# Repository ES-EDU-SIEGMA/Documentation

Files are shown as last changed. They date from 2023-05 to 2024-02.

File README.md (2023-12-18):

# Drink Mixing Machine

This is the project repository of the Drink Mixing Machine.

## Structure

The code for the controller can be found under [Embedded Controller](https://github.com/ES-EDU-SIEGMA/Embedded-Controller), whereas the GUI code can found under [User Interface](https://github.com/ES-EDU-SIEGMA/User-Interface).

The documentation of the hardware and software is provided in this Repository under [documentation](./documentation).
Referenced Datasheets for the Hardware are stored under [datasheets](./datasheets).

The CAD/STL files for the 3D printed parts are stored in the [3D printed parts](./3D_printed_parts) folder.

## Issues

The issues and user stories can be found under [Projects Board](https://github.com/orgs/ES-EDU-SIEGMA/projects/1).
Each Issue is connected to a Repository which it concerns.

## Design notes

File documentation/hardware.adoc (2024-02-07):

= Hardware
:icons: font
:toc: top
:toclevels: 4
:stem:
:imagesdir: images
:figure-caption!:

The Drink Mixing Machine consists of several hardware parts.
There can be grouped into three categories, namely:

* <<Frame,Frame>>
* <<Dispenser Components,Dispenser Components>>
* <<Controlling Components,Controlling Components>>

== Frame

The frame is build from aluminium bases system profiles.

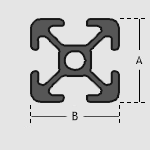
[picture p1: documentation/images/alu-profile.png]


== Dispenser Components

The dispenser group consists of multiple components arranged around a standard bar dispenser as seen in <<dispenser-img,Dispenser Image>>.

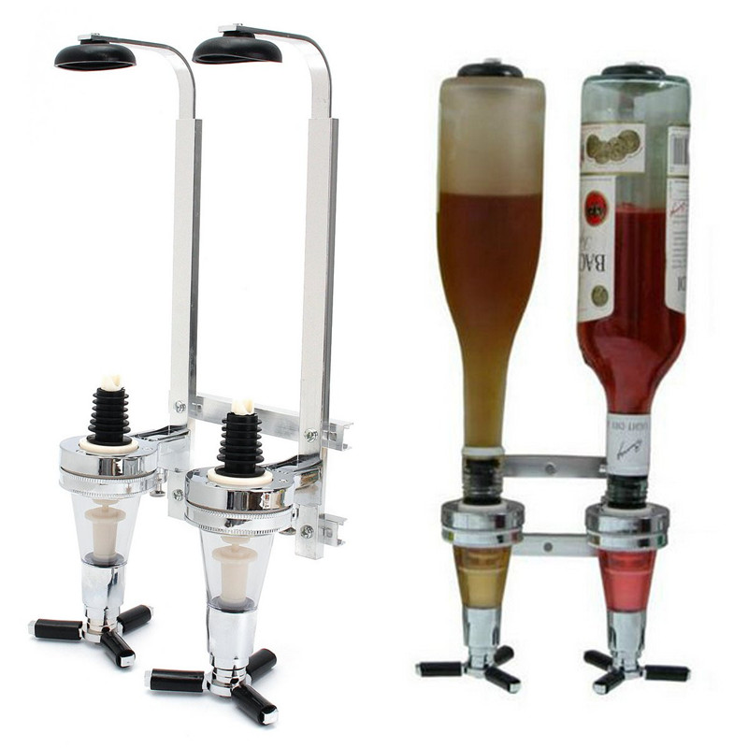
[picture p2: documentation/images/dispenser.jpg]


The dispenser is actuated by a 3D-printed arm which is lifted with a construction of ropes and pulleys powered by a stepper motor as the winch.

=== Metrics

.Manual Operation
====
3 to 5 seconds for the Dispenser to drain the liquid +
**=> 4 to 6 seconds to empty the Dispenser**
====

.With the Machine
====
With a `VACTUAL` (<<TMC2209>>) of 5000 latexmath:[\frac{\mu\text{-steps}}{\text{second}}], the dispenser requires 8 seconds to move up and 8 to move down +
**=> latexmath:[\geq] 16 seconds to empty a Dispenser**

The highest speed that the motor can achieve is `VACTUAL` = 150000 latexmath:[\frac{\mu\text{-steps}}{t}]. With this speed it takes only 6.5 seconds to empty and refill a 4 cl Dispenser.
However, these speeds can only be achieved with a more stable mechanical system. 
Currently, the plastic bottle holders bend to much at higher speeds.
If the dispensers are held from above when starting the motor, it is possible to start up with 150000 latexmath:[\frac{\mu\text{-steps}}{t}]. 
Metal components with a proper attachment to the machine might fix this problem.

IMPORTANT: The current mechanical system allows for speeds of up to  `VACTUAL` = 100000 latexmath:[\frac{\mu\text{-steps}}{t}] for reliable emptying of the dispenser. +
**=> 8 seconds to empty a Dispener**

CAUTION: Slow movement when closing is required in order to assure that the Dispenser is refilled. 
`VACTUAL` = 100000 latexmath:[\frac{\mu\text{-steps}}{t}] should not be exceeded.
====

.Estimated Times to fill a 250ml glass
|===
|Dispenser |Manual Operation |Machine `VACTUAL`=50000 |Machine `VACTUAL`=100000

|3cl |30s |90s |45s

|4cl |24s |72s |36s

|5cl |18s |54s |27s
|===

TIP: 5cl Dispenser can significantly reduce the time required to dispense liquids with large amounts.

==== Real World Test

.Mixing a Cocktail with 5 ingredients:
- 3 ingredients require 2cl each
- 2 ingredients require 10cl each

-> two runs are required with each 18 seconds +
**=> 36 seconds**

=== Improvements

The accuracy of the dispensing mechanism mostly depends on the volume of the dispenser.
Due to hardware restrictions it is extremely difficult to precisely empty the dispenser only partially.

TIP: After improvements to the movement speeds of the motor experiments should take place, that evaluates the possibilty of emptying the dispenser only partially.

== Controlling Components

The controlling components of the machine are a Raspberry Pi (as the main controller) combined with a custom PCB that features a Tiny2040 as a controller for up to 4 stepper drivers and multiple sensors.

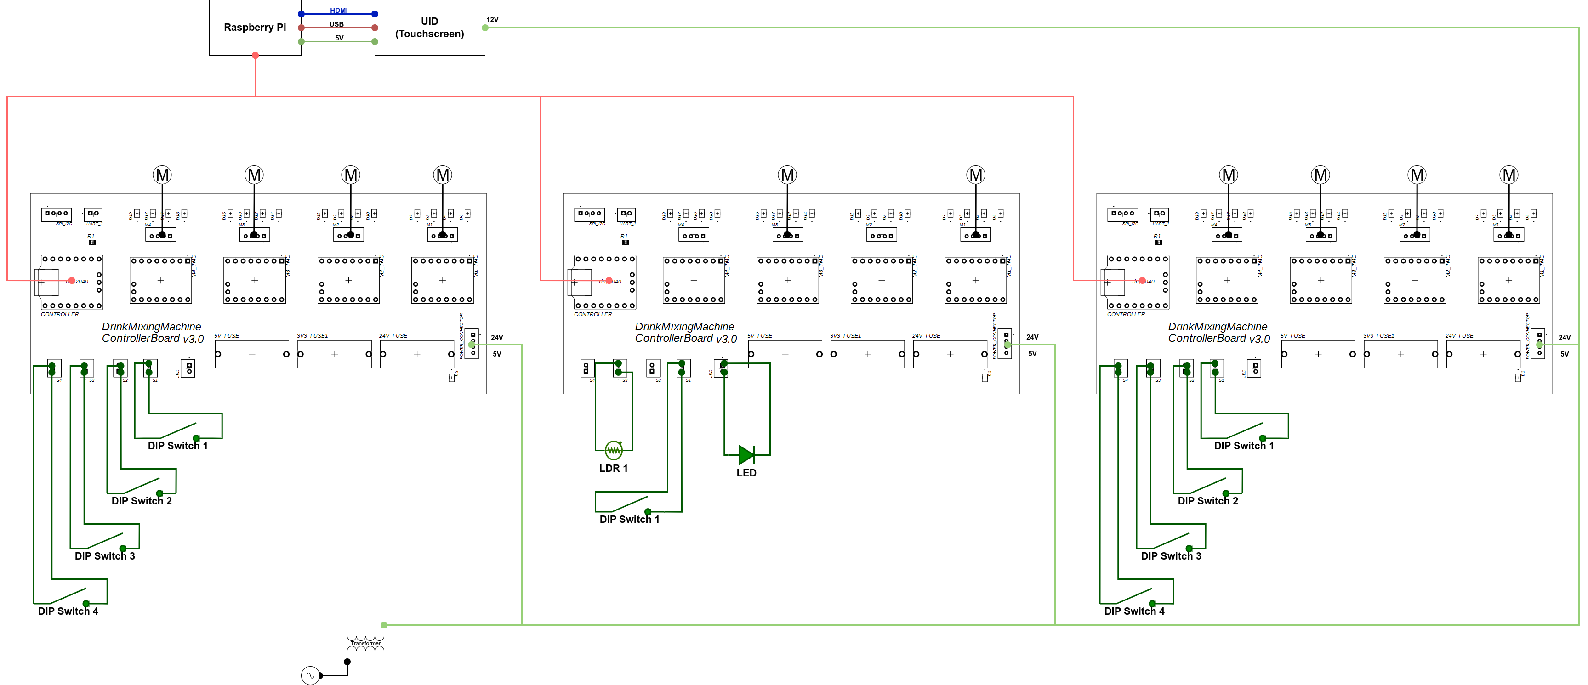
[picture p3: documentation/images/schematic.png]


=== Raspberry Pi

The Raspberry Pi provides the GUI for the user and holds the required database for the drinks and ingredients.

The Tiny2040 on the PCBs are connected to the Raspberry Pi via a serial port which are mapped dynamically during runtime.

The scale under the jar is directly connected to the Raspberry Pi via GPIOs.

==== Scale

The scale unit consists of a beam scale combined with an ADC.

[horizontal]
Beam Scale::
    The beam scale provides us with a continues analogue signal that has to be converted to a digital signal.
ADC::
    The ADC converts the analogue signal from the beam scale to a digital signal, that can be used by interpreted digital GPIO pins of the Raspberry PI.
    The Drink mixing machine utilizes the HX711 ADC chip, which is specialized in converting analogue data from a scale.
HX711:::
    The HX711 can be used with a throughput of 10 *or* 80 samples per second and provides a active low noise programmable gain amplifier (gain = 32, 64, 128).
    Each sample consists of a 24 bit value provided in twos-complement.
Software::
    The software library used is  the https://github.com/tatobari/hx711py[tatobari/hx711py] library.
    To get correct values from the scale the library requires the user to specify a `REFERENCE_UNIT`.
    This value is the factor that scales the received value and has to be determined by experimentation with the setup, as described in https://github.com/tatobari/hx711py/blob/master/example.py[libraries example.py].

IMPORTANT: `REFERENCE_UNIT` has to be reevaluated when the module is changed *or* when the chip is changed!

=== PCB

NOTE: The Eagle project files can be found the https://github.com/ES-EDU-SIEGMA/Embedded-Controller/tree/main/PCB[Embedded-Controller Repository]

The PCB is custom made for this machine.





[horizontal]
CONTROLLER::
    Tiny2040 Compute Module
POWER_CONNECTOR::
    Power connection for the PCB
S1-S4::
    Endpoints for sensor connections
LED::
    LED for LDR sensor of the rondell
UART_1::
    Debug point for the one-wire UART to the TMC Motor Drivers
SPI_I2C::
    Breakouts to connect the Tiny2040 via SPI or I^2^C to the Raspberry Pi

.Datasheets
* link:../datasheets/TMC2209_datasheet_rev1.09.pdf[TMC2209]
* link:../datasheets/TMC2209_SilentStepStick_Rev110.pdf[TMC2209 SilentStepKick Board]
* link:https://shop.pimoroni.com/products/tiny-2040[Tiny2040]
* link:../datasheets/rp2040-datasheet.pdf[RP2040]

==== TMC2209

The stepper motors are currently operated using the `VELOCITY DEPENDENT DRIVER FEATURE CONTROL REGISTER`.
So far the motors have been operated at a speed `VACTUAL` of 50000 latexmath:[\frac{\mu\text-steps}{t}], with a CLK frequency of 12 MHz each step would take latexmath:[t=2^{24}\cdot CLK^{1}	=	1.398101] seconds.

NOTE: With this speed the motor needs 8 seconds to fully open the dispenser.

The latexmath:[\mu\text{-steps}] velocity v in Hertz can be determined using the formula:
[latexmath]
++++
v = \frac{VACTUAL \cdot CLK}{2^{24}}
++++

To determine how many latexmath:[\mu\text{-steps}] it takes the motor to fully open the dispenser, the following formula is used.

[latexmath]
++++
v \cdot t
++++

[example]
====
For `CLK` frequency of 12MHZ and a `VACTUAL` of 50000 the formula is:
[latexmath]
++++
v = 50000 \cdot 0.715Hz = 35762.79\frac{\mu\text{-steps}}{\text{second}}
++++

Therefore 
[latexmath]
++++
8\;\text{seconds}\cdot v = 8\;\text{seconds}\cdot 35762.79\frac{\mu\text{-steps}}{\text{second}} = 286102\mu\text{-steps}
++++
are required to fully open of the dispenser.
====

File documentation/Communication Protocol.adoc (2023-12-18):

= Communication Protocol
:icons: font
:toc: top
:toclevels: 4
:stem:
:imagesdir: images
:figure-caption!:

The communication protocol defines the messages exchanged between the Rapsberry Pi (UI/Master) and the Tiny2040 (Stepper Controller).

== Commands

[cols=">,<",options="header",]
|===
|Command |Description

|`i`
|Request identifier

|`LEFT`
|Identifier for left controller

|`RIGHT`
|Identifier for right controller

|`RONDELL`
|Identifier for rondell controller

|`F`
|Signals wrong command

|`CALIBRATED`
|Hardware is calibrated and ready to be used

|`READY`
|Message was handled and waiting for next command

|`int;int;int;int;`
|Sequence of drink dispensing
|===

== Syntax

Standard Syntax::
    `<command>\n`

Dispense liquids::
    `<halt_time_dispenser_1>;<halt_time_dispenser_2>;<halt_time_dispenser_3>;<halt_time_dispenser_4>;\n`

====
Message:: `5000;11500;0;0;\n`

.Declaration
* Dispenser 1 opens for 5000ms
* Dispenser 2 opens for 11500ms
* Dispenser 3 opens for 0ms
* Dispenser 4 opens for 0ms
====

== Communication Sequence

ifdef::env-github[]
[source,mermaid]
endif::[]
ifndef::env-github[]
[mermaid,format=svg]
endif::[]
----
sequenceDiagram
participant server as Rapsberry Pi
participant controller as Tiny2040

    server ->> controller: i
    alt is rondell
        controller->>server: RONDELL
    else is left
        controller->>server: LEFT
    else is right
        controller->>server: RIGHT
    end

    note over controller: Run Calibration for home position
    controller->>server: CALIBRATED

    loop forever
        note over controller: waiting for dispense command
        server->>controller: int#59;int#59;int#59;int#59;
        note over controller: dispense liquids
        controller->>server: READY
    end
----

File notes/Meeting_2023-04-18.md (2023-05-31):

# Meeting: 2023-04-18

We shouldn **not write a new code** unless we can justify it well!

Every **two weeks**, we will select **a new sprint leader**.
**David** was appointed as the current sprint leader **till 01.05.2023**.

During the meeting, we discussed the customer's requirements and identified them by priority:

0. Ensuring **food safety** (We should consider related material standards.)
1. **Easy to clean**
2. **60-seconds** operation time after choosing a drink
3. Accurate dosing (± 5 ml)
4. **Recipe** insertion and modification ability
5. collect, store, and show **statistics** of the types of drinks made(user statistics), and the machine status(Hardware statistics for maintenance)
6. Dispense **Sparkling Drinks**
7. Split Admin and Gust View or **User rights** (**We must ask for more details**)
8. Improve **User Interface** for an enjoyable usage
9. Dispense **milk**

- [x] Then, we converted customer these requirements into user stories and created them on GitLab. We also created templates for user stories, which consist of three parts: role, action, and purpose.
- [x] We derived tasks from the user stories and also noted them in GitLab.

food safety should always be given top priority, and cleaning would be a trade-off with usability, which we would need to balance.

**The first iteration** will be a system test, which will involve getting the mixer to work with the software.

- [x] We scheduled a system test for Friday.

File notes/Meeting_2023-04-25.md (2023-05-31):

# Meeting: 2023-04-25

## 0. IoT-Garage

Arbeitsbereich auf einen Tisch reduzieren

## 1. Limiterfehler

Der Motor, der den Mixerarm (bzw. Dispenser Hebel) steuert, wird irgendwie bei der Initialisierung nicht gestoppt, so dass der der Arm nicht in die "home-position" (Kaptiel 3, Workflow, S. 7) kommt.
Entweder ist der zugerhörige Limiter bzw. Endschalter defekt oder es liegt ein Softwarefehler vor.

-> Limiter funktioniert (Board war falsch zusammen gesteckt)
-> Initialisierung muss noch getestet werden

## 2. Python-Code für GUI

Laut Lewakis (Kapitel 2, System Design, Seite 6) ist der Touch-Screen mit dem Raspberry Pi über den Touch-Port verbunden.
Ich habe auf den Seiten von PyQt keine Hinweise gefunden, dass die gui besonders programmiert werden muss, um sie mit Maus und Monitor oder Touch-Screen bentzen zu können. Es wird keinen Unterschied gemacht.

## 3. Verfeinerung Uses-Case auf Grundalge der Python-GUI:

Eine Getränk auswählen und Zubereitung am Automaten starten

https://git.uni-due.de/embedded-systems/student-projects/ss23-drink-mixing-machine/main/-/wikis/Vorschlag:-L%C3%B6sung-f%C3%BCr-erste-Iteration,-Verwendung-vorhandenen-Codes,-neues-C-Interface

> weitere Themen bitte hier hinzufügen ...

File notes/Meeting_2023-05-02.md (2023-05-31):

# Meeting: 2023-05-02

## Aktueller Stand

- Die Drink-Mixing-Maschine kann mit übernommener Software gestartet werden.
- Die Hardware der Maschine ist teilweise beschriftet.
- Es existiert ein Klassendiagramm für die gui-codebasis, das die Abhängigkeiten zwischen den Klassen zeigt.
- Für die gui-codebasis wird Test-Driven Refactoring angewendet.
- Die Datenbank wurde durch eine JSON-Datei ersetzt, in der die Daten gespeichert werden.
- Es gibt jetzt gleichartige Dispenser mit einem gleichem Fassungsvermögen von jeweils 4 ml.

## Neuere Anforderungen

- Der Kunde will wissen, welche Flasche ausgetauscht werden muss.
- Der Kunde will sicherstellen, dass der Gast nur Getränke mit verfügbaren Zutaten herstellen kann oder dass der Gast Getränk nach seinen individuellen Wünschen anpassen kann.
- Der Kunde will, dass die Getränkegröße und die Eismenge automatisch bestimmt werden.
  - Für den Anfang gehen wir aber von einer Einheitsgröße von 350 ml aus.
- Der Kunde möchte eine einfache und sichere Authentifizierungsmethode, um sicherzustellen, dass nur befugte Personen auf das Adminfenster zugreifen können. (Chip, PIN)

## Aufgaben

> siehe auch Boards

- Python-Code Refactoring
- C-Code
- Metriken für physikalische Komponenten
- Zum nächsten Meeting müssen wir **etwas Konkretes** an der Maschine demonstrieren
  - einen bestimmten Dispenser öffnen und schließen
  - weitere Ideen hier ...

> Bislang gelpantes Treffen zum Testen: Dienstag vor dem Meeting um 12:00 oder früher.`

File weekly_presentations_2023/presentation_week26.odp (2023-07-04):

## Presentation week (27.06-04.07)

-python code documentation

-soldering pcb board rondel

-display

-test food safe material

-startposition hopper lever

-ramp function

## python code documenation @Markus

- checked comments in code
- reworked markdown readme
- added some simple graphics

## soldering pcb board rondel @Markus

- finished pcb board rondel

## display @David

- display mount printed

## test food safe materials @David

- test the food safety of the filament

## ramp function @Kamilloo

- test c code ramp function on hardware.

## startposition hopper lever @Kamilloo

- work on recognizing the correct startposition through measuring power consumption.

## idea 1

- create a hole for some weights in the lever.

## Idea 2

- let the pi reconnect to the tiny.
- problem: after the tinys are identified, a tiny connection can’t be reestablished without reseting the tiny.
- allow the pi to reestablish a tiny connection without manually reseting the tinyhe tiny

## Idea 3

- question: should we add error handling to the pi when a communication error occurs?
- the tiny sends an error signal to the pi but the pi doesn’t use it in any way.
- but so far no significant communication errors have occured.

## result of last weeks planning

  color coded progress of a plan:
- not done
- progress
- finished

## plans last week part 1

- adding display to the machine @David
- soldering rondell pcb board @Markus
- rewiring and connecting pcb boards
- print food safe materials @David
- test scale value accuracy

## plans last week part 2

- test c code (ramp-function) @Kamilloo
- write python documentation @Markus
- test food safe filament @David

## plans next week

- rewiring and connecting pcb boards
- print food safe materials @David
- test scale value accuracy
- adding display to the machine @David

## feedback leo

- clarify which user story is part of a problem
- focus on the user story 60 seconds to drink
- prioritize having the machine in a running state

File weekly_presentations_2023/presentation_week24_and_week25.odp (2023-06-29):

## Presentation

-pair programming python code

-motor speed

-rewiring the machine

-progress display

-soldering pcb boards

-test printing food safe materials

-ramp function

-progress ramp function

## Pair programming (13.06-20.06) @David, @Markus

- testing the python code
- fixing errors
- scale integration tests
- fixing hopper timings
- getting the code running on the pi
- python code got merged into main and finished

## motor speed (13.06-20-06) @Kamilloo

- new feature: 2 different motor speeds (slow, fast)
- the motor speed is controlled with a constant in the c-code

## rewiring the machine (20.06-27.06) @David

- progress on cable management
- add pico holders to the machine
- adjust transformer output
- todo: connect pcb boards to the machine
- todo: rewire power supply

## progress display (20.06-27.06) @David

- progress on disply mount
- cut out display backside plexiglass shield
- todo: cut display to the right size.
- todo: finish display mount
- todo: add display and plexiglass to the machine

## soldering pcb boards (20.06-27.06) @Markus

- completed one pcb board
- progress on rondell pcb board
- todo: complete rondell pcb board

## food safe materials (20.06-27.06) @David

- finished test printing food safe materials
- todo: print machine parts with food safe material

## ramp function (13.06-27.06) @kamilloo

- progress on ramp function
- new feature: 2 speeds for the ramp function
- todo: test ramp function code on hardware

## Idea

- let the hopper arm be closer to the dispenser
- goal: reduce the dispense time by reducing the length the hopper arm has to move.

## plans (27.06-04.07)

- adding display to the machine @David
- soldering rondell pcb board @Markus
- rewiring and connecting pcb boards
- print food safe materials @David
- test scale value accuracy
- test c code (ramp-function) @Kamilloo
- write python documentation @Markus

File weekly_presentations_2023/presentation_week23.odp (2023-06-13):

## Topics weekly meeting

- cabel management

- display

- hopper motor

- hx711 documentation

- python code progress

## cabel management

- In progress: soldering of connectors onto the pcb boards.
- finished: printing cable holder clips
- finished: better cable layout

## display

- plexiglass backside display cover is finished
- todo: add plexiglass backside cover to the machine.
- todo: add display to the machine

## hopper motor oprimization idea

- proposal: implement a ramp function for the motor.
- goal: reduce the tilting of the hopper at high motor speeds.
- assumption: with a ramp function the hopper might not tilt as much on higher motor speeds.

## hx711 documentation

- todo: add hx711 documentation to the project documentation.

## python code progress

- code runs locally with hardware mocks on a console
- code that accesses hardware needs to be tested.
- added configuration file
- unittest full test coverage in progress

## todo

- add further unittests
- add feature remove ingredient from hopper
- add feature use ingredient fill amount
- add touchscreen gui

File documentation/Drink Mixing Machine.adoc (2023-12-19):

= Drink Mixing Machine
:icons: font
:toc: top
:toclevels: 4
:stem:
:imagesdir: images
:figure-caption!:

The application shows a list of available drinks from which the guest can choose.
After the selection the application retrieves all flow speeds from the database and calcualtes the time required for dispensing the beverages alongside with the count of dischareges required to fill the glass.
The timings will be send to the Controller on each PCB as often as the dispensr has to be emptied.

During the dispensing of the drinks the display provides a progress report based on scale underneath the glass of the guest.
This requires the scale to be tared before every drink dispensing.

== Glossar

.Roles
[cols=">,<", options="header"]
|===
|Role |Definition
|Owner |Person who owns of the machine (Leo) (administrator rights)
|Privileged User |Person who has extended user rights
|Guest |Person who wants to get a drink (basic user rights)
|Cleaner |Person who cleans the machine
|Bottle Changer |Person who changes the beverages
|Developer |Person who develops software/hardware for the machine
|===

.Components
[cols=">,<", options="header"]
|===
|Term |Definition
|Dispenser |manual dosing device
|mix |pouring beverages together
|Recipe |Specification for creating a beverage
|Ingredients |Beverages like Milk, Alcohol, Water, Sirup, Juice, ...; in standard commercial bottles
|===

== Sequence Diagram: Dispense Drink

ifdef::env-github[]
[source,mermaid]
endif::[]
ifndef::env-github[]
[mermaid,format=svg]
endif::[]
----
sequenceDiagram
    participant Guest
    participant UI as User Interface
    participant PI as Raspberry Pi
    participant DB as Data Storage
    participant CONTROLLER as Tiny2040

    UI->>PI: Get Available Drinks
    PI->>UI: Show Drinks
    Guest->>UI: Select Drink
    UI->>PI: Forward Selected Drink
    PI->>DB: Request Drink Information
    DB->>PI: Send Drink Info
    PI->>PI: Calculate activation time for dispenser
    PI->>PI: Tare Scale
    PI->>CONTROLLER: Send Activation Time For Dispenser
    CONTROLLER->>+CONTROLLER: Start Dispensing Beverages
    par Update UI
        loop Until Glass Full
            PI->>PI: Get Weight from Scale
            PI->>UI: Show Progress
        end
    and Upate from Tiny2040
        CONTROLLER->>-PI: Finish Dispenesning Beverages
    end
    alt Dispenesning Successful
        PI->>UI: Show Finish Message
    else otherwise
        PI->>UI: Show Error Message
    end
----

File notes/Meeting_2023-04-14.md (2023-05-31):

# Meeting: 2023-04-14

## Orga

Lukas ist vorerst unser Teamleiter, Leo unser Auftraggeber.

**Neuer Termin:** Wir treffen uns vorerst jede Woche dienstags um 14:00 Uhr.

## Ziel des Projektes

Unser **Hauptziel** in dieser Phase des Projekts: die Anforderungen an das System herausbekommen durch Hinterfragen von Leos Wünschen. Ggf. Leo Alternativen vorschlagen und Anforderungen verfeinern, bis implementierbare Stufe erreicht ist.

Unsere **Aufgabe** bis nächsten Dienstag: Dokumente querlesen, übergebenen Code compilieren und eventuelle Fehlermeldungen und überlegte Lösungsschritte dokumentieren. Ziel: feststellen, welche Anforderungen bereits erfüllt sind.

Leo hat eine Getränkemischautomat für Säfte und alkoholische Getränke entwickelt und will jetzt den Automaten verbessern, um ihn bei einer Party in einer Wohung oder im Garten einsetzen zu können.

Dafür stellt er uns Dokumente zur Verfügung und bereits geschriebenen Code.

## User-Story

Seine wichtigste Anforderungen sind, das Gerät soll zuverlässig dosierte Getränke in 30 Sekunden nach Auswahl eines Rezpets über das Bedienelement durch einen Gast bereitstellen. Die Dosierung sollte dabei auf hunderstel Liter (cl) genau sein.

Weiter ist ihm wichtig, Statistiken über die Nutzung des Geräts zu erhalten über ein Webinterface oder eine App. Insbesondere möchte er Daten über die Motoren haben und welche Getränke am liebsten zu welchem Anlass getrunken wurden.

Später soll ein Gasdrucksystem dazukommen, um Getränke mit Kohlensäure anzureichern und die Ausschenkzeit zu verkürzen. Weiter sollen später Getränke in den Schläuchen gekühlt werden können.

Und die GUI könnte überarbeitet werden. Beispielsweise findet er die Bedingung über den Scrollbalken suboptimal. Die Adminsicht sollte verschieden sein von der Nutzersicht.

Letztlich ist es ihm wichtig, dass er Rezepte in das System eingeben kann.

## Informationen

Eingeführte Rollen/Begriffe: siehe documentation/glossar.md

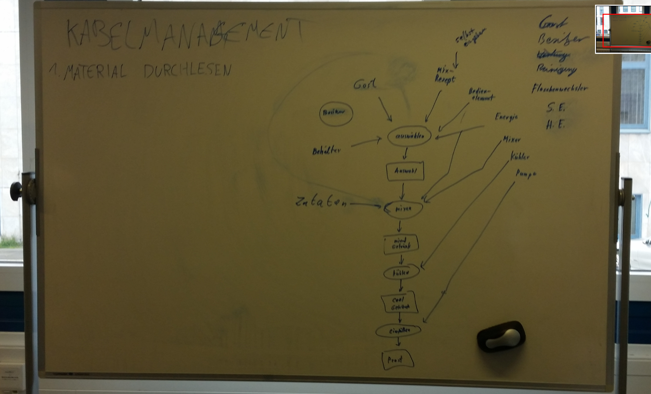
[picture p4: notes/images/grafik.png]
Bild: Programmablauf


Das Gerät hat Rezepte gespeichert.
Diese Rezpete werden einem Gast über ein Display angezeigt Der Gast kann über ein Bedienelement ein Rezept auswählen und dann die Zubereitung starten.
Die Getränke werden nach Rezept im Trichter gemischt und über die Gewichtskraft in das Glas des Gastes eingefüllt.

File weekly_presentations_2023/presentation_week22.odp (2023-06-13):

## Themen weekly meeting

- Neues Display

- Kabelmanagment

- github migration

- Motor max. geschwindigkeit

- Food safety filament tests

- Python code refactoring konzept

- Python code refactoring fortschritt

## Neues Display

- Neues Display ist angekommen, erfolgreich eigebaut und funktioniert.
- Plan ist eine Rückblende (aus Plexiglas) einzubauen um das Display vor Flüssigkeiten zu schützen.

## Kabelmanagement

- Plastik-kabelhalter sind gedruckt/ werden gedruckt und müssen noch eingebaut werden.
- Plan: Kabel in der Maschine besser positionieren.

## github migration

- Die repositories und offenen issues wurden erfolgreich nach github übertragen.

## Motor max. geschwindigkeit

- Time from depletion and refill for 4cl at max speed is 6.5sec.
- But the plastic holder bends at max speed significantly and makes such a depletion currently impossible.
- Idea: Fix bottles and hoppers with a better system to the machine to reduce bending.

## Verbesserung zur Ausleerungs geschwindigkeit

- Einbauen von Federn oder Federn um das zurückfahren zu verbessern.

## Foodsafety tests

- Lebensmittelechtes filament wurde bestellt
- Ziel ist es zu testen ob Trichter gedruckt aus derartigen Material vergleichbare Materialeigenschaften haben und für die Maschine zu gebrauchen sind.

## Probleme mit python code

- Das Programm weist keine nennenswerte modularisierung auf.
- Datenmodell ist übermäßig komplex.
- Datenmodell ist schwierig erweiterbar.
- Viele Methoden erhalten mehr Daten in Form von Objekten als sie benötigen.
- Programm logik ist tief in der GUI verbaut.

## Python code refactoring Konzept

- Idee ist den code in kleine unabhängige Module zu unterteilen, damit mehrere Personen unabhängig von einander am code arbeiten können.
- Ziel ist es schnittstellen zu definieren, so dass jeder in einem modul bei der implementierung nur die schnittstellen beachten muss
- Der code für Wage und serial-communication kann großteils wiederverwendet werden.

## Modules

- GUI
- Data
- Controller bzw. logic
- Scale
- Communication
- Calculate Timings

## GUI

  // Gui bietet keine Methoden an

## Data

def get_ingredient_names(self) -> list[str]

def get_recipe_names(self) -> list[str]

def get_ingredient_on_hopper_names(self) -> list[str]

def get_recipe_dispensable_names(self) -> list[str]

def set_hopper(self, __hopper_position: int, __new_beverage_on_hopper_name: str)

def create_recipe(self, __new_recipe_input: dict)

## Controller bzw. logic

def cmd_dispense_drink(self, __drink_name: str):

def cmd_get_weight(self) -> int:

## Scale

def get_weight(self) -> int:

## Communication

def activate_hoppers(self, __hopper_positions: list[int], __timings: list[int])

## Calculate Timings

def calculate_time(self, __amount: int) -> int:

## Python code refactoring fortschritt

- Fertig sind: Daten, GUI(Konsole) und die Verbindung beider
- Noch offen: Wage, Hopper, Berechnung der Timings, GUI(PyQt)
- Zeit einschätzung: 1 Woche (ausgenommen GUI PyQt +1Woche)

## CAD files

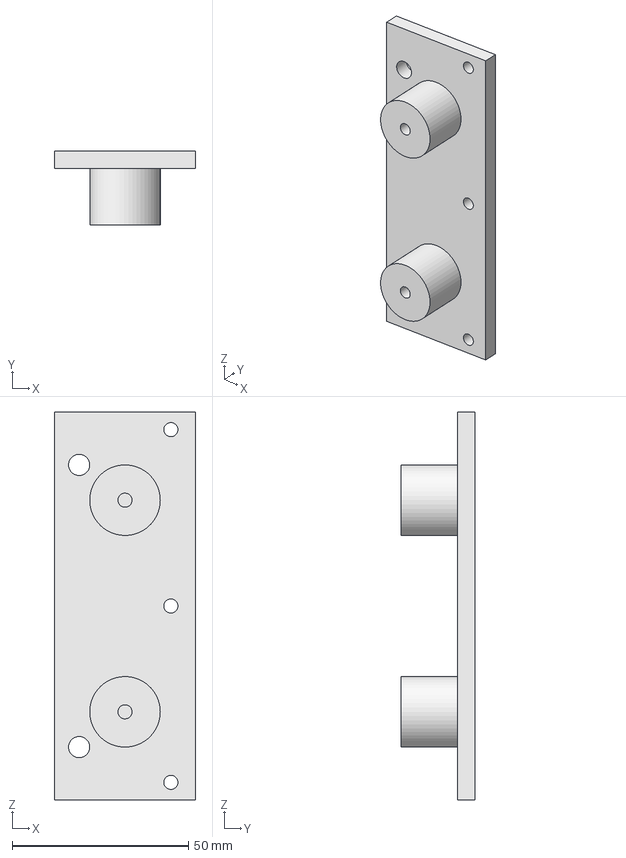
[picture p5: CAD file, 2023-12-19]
3D_printed_parts/FreeCAD_Files/display_bracket.FCStd
40.0 x 21.0 x 110.0 mm

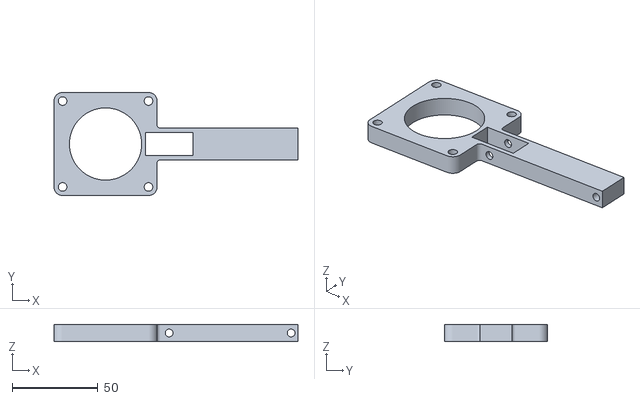
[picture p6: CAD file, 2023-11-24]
3D_printed_parts/STL_Files/Leverage-small.stl
142.0 x 60.0 x 10.0

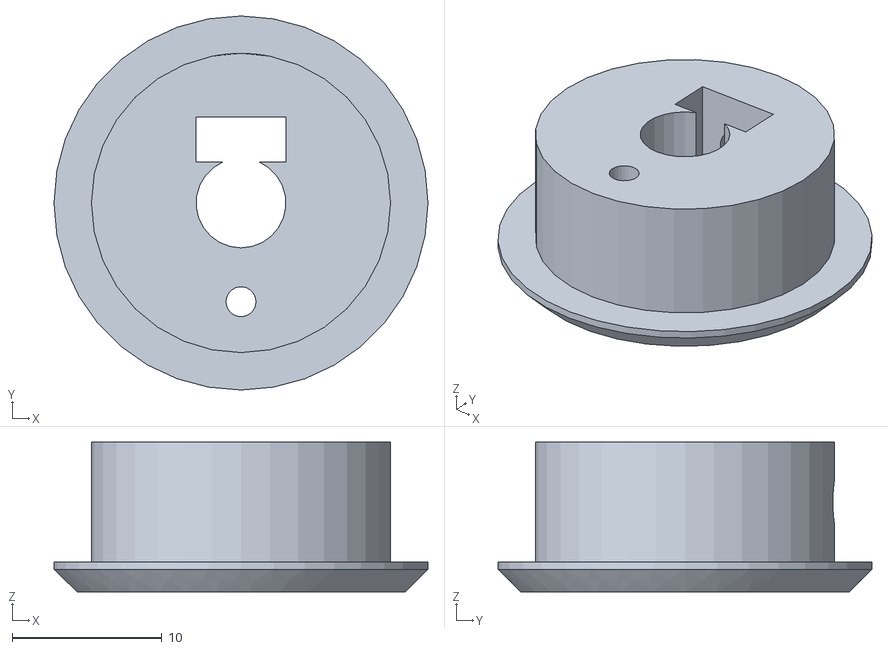
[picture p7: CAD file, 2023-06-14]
3D_printed_parts/STL_Files/Rope Bracket (Motor).stl
25.0 x 25.0 x 10.0

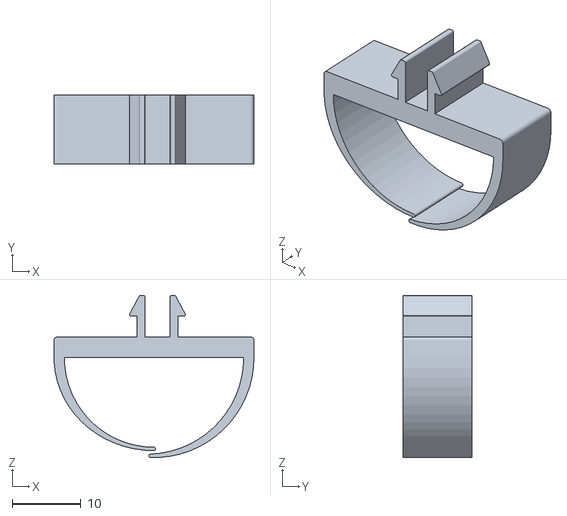
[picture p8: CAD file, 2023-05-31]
3D_printed_parts/STL_Files/Item_cable_mounting_30mm.STL
29.0 x 10.0 x 23.5

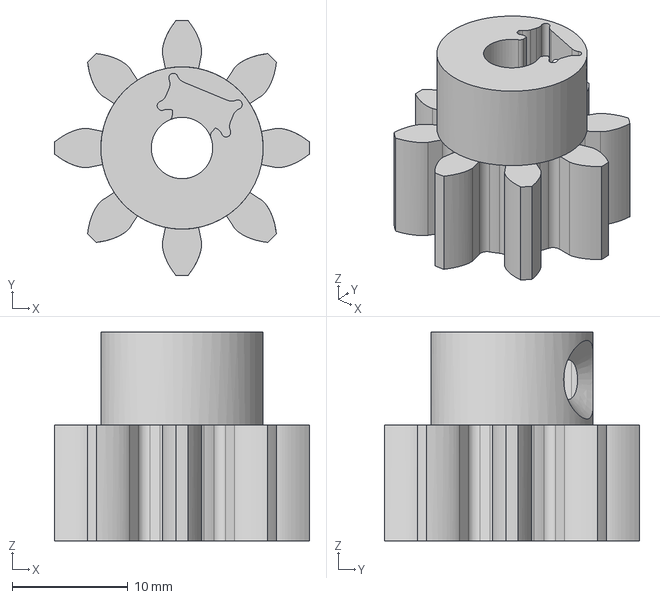
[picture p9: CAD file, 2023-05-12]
3D_printed_parts/FreeCAD_Files/Spur Gear (8 teeth).step
22.0 x 22.0 x 18.0 mm

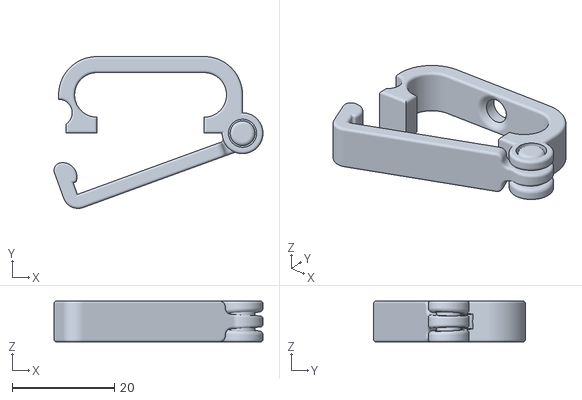
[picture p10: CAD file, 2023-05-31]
3D_printed_parts/STL_Files/CABLE_CLIP_V6.2.stl
40.9 x 29.7 x 8.00

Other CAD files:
3D_printed_parts/FreeCAD_Files/dispenser_leverage.FCStd
3D_printed_parts/FreeCAD_Files/rope_bracket.FCStd
3D_printed_parts/Inventor_Files/2.01.01-000 Dispensergruppe v27.iam
3D_printed_parts/Inventor_Files/2.01.01-001 Dispensergruppe_Basis(Mirror).ipt
3D_printed_parts/Inventor_Files/2.01.01-001 Dispensergruppe_Basis.ipt
3D_printed_parts/Inventor_Files/2.01.01-002 Dispensergruppe_Stange_A(Mirror).ipt
3D_printed_parts/Inventor_Files/2.01.01-002 Dispensergruppe_Stange_A.ipt
3D_printed_parts/Inventor_Files/2.01.01-002 Dispensergruppe_Stange_A_1.ipt
3D_printed_parts/Inventor_Files/2.01.01-003 Dispensergruppe_Stange_B(Mirror).ipt
3D_printed_parts/Inventor_Files/2.01.01-003 Dispensergruppe_Stange_B.ipt
3D_printed_parts/Inventor_Files/2.01.01-003 Dispensergruppe_Stange_B_1.ipt
3D_printed_parts/Inventor_Files/2.01.01-004 Dispensergruppe_Gummideckel(Mirror).ipt
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

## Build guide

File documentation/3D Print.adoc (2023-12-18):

= Hardware
:icons: font
:toc: top
:toclevels: 4
:stem:
:imagesdir: images
:figure-caption!:

== Files

CAD models for different parts of the machine can be found under link:../3D_printed_parts[3D_printed_parts].

The required STL files for some parts can be found under link:../3D_printed_parts/STL_Files[STL_Files].
These files can be used as input for the printer controlling software to directly print these parts.

== Best Results

TIP: The SLA printer provides a more dense/stable result

Gears and Pulleys should be printed with the SLA printer to obtain the best results. 

IMPORTANT: Moveable parts like the Cable Clips can only be printed with the FLM printer

== Food Safety

Standard filaments/resins are not qualified for food safety prints, due to the fact, that this materials emit toxic components into the beverages.

The solution to this problem would be to use a Filament that is approved by the EU/FDA to be food safety.
Such Filaments can for example be bought by manufacturers like BASF:

https://www.igo3d.com/innofil3d-epr-pet-175-weiss-2500[PET based Filament]::
*  same material as water bottles
* Developed by Innofil3D (purchased by BASF)
* Approved by the EU and FDA

https://www.igo3d.com/innofil3d-pp-175-natur-700[PP based Filament]::
* Polypropylen
* Developed by Innofil3D (purchased by BASF)
* Approved by EU and FDA

== Sources
* https://formlabs.com/blog/guide-to-food-safe-3d-printing/[]

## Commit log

2023-05-07 docs(hardware): add schematics for electric
2023-05-12 chore(3d-print): restructured files
    [2.01.01-000 Dispensergruppe v27.iam, 2.01.01-001 Dispensergruppe_Basis(Mirror).ipt, 2.01.01-001 Dispensergruppe_Basis.ipt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]
2023-05-14 feat(3D-print): added rope bracket
    [Rope Bracket (Motor).stl, rope_bracket.FCStd]
2023-05-31 docs: added meetings notes from gitlab
    [CABLE_CLIP_V6.2.stl, Item_cable_mounting_30mm.STL]
2023-06-01 docs(3d-print): added documentation for 3D printing
2023-06-14 fix(hardware): update wrire schematics
2023-06-14 feat(3D-print): update rope bracket
    [Rope Bracket (Motor).stl]
2023-07-09 Create TorqueData4clDispenser
2023-07-09 Create TorqueData3clDispenser
2023-10-31 Schematic of the PCB
2023-11-07 Add files via upload
    Time consumption and torque value after optimizing processMessage function. See issue #41
2023-11-07 Data TMC2209_read: time of reading via UART
2023-11-09 Create TorqueDataOneDispenser
2023-11-12 docs(hardware): add motor datasheet
    Datasheet of the motor of Usongshine 17HS4401
2023-11-14 Delete documentation/TorqueData/2023.11.14-delay test 6-115200.log
    Things went wrong when I enabled the clock counting in processMessage, need more tests.
2023-11-24 fix(lever): adjust winch tunnel
    [Leverage-small.stl, dispenser_leverage.FCStd]
2023-11-24 fix(display-bracket): update display bracket
    [Display Bracket.stl, display_bracket.FCStd]
2023-12-19 fix(display-bracket): fix display bracket
    [Display Bracket.stl, display_bracket.FCStd]
2024-02-07 docs(pcb): update schematics
